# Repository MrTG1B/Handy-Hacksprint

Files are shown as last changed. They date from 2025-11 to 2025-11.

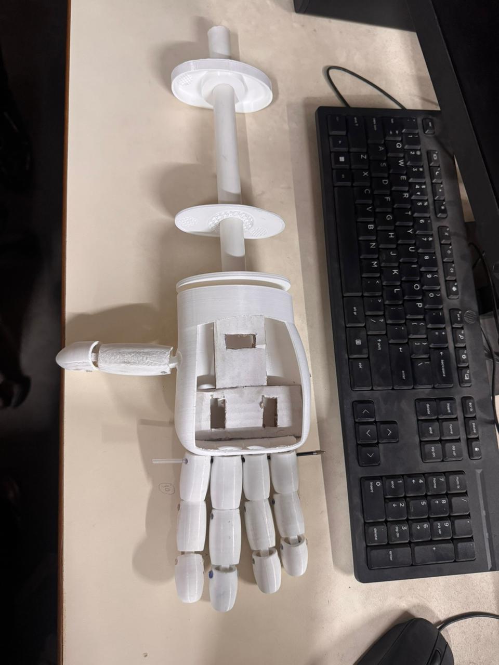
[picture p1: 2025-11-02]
Media/Handy- shell 2.jpg

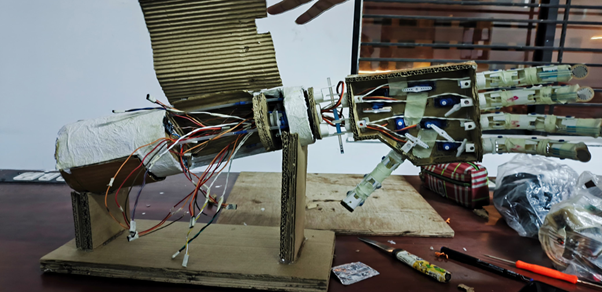
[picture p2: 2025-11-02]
Media/Handy- cardboard prototype.png

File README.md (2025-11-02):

# 🦾 Affordable & Functional Upper Limb Prosthetic Terminal Device  

### Development of an Affordable and Functional Upper Limb Prosthetic Terminal Device for Partial Hand Amputees  

This project aims to develop a **cost-effective, mechanically operated prosthetic terminal device (hand)** for upper limb amputees — bridging the gap between **high-cost myoelectric prostheses** and **low-function body-powered devices**.  

A large number of patients in India, especially in **rural and semi-urban regions**, remain underserved due to the lack of affordable and functional prosthetic devices.  
This project addresses that need directly.  

---

## 🎯 The Problem  

High-cost myoelectric prostheses are **financially inaccessible** for many, while **basic body-powered hooks** offer limited functionality and cosmetic appeal.  
There is a significant need for a device that is:  

- 💸 **Affordable:** Accessible to patients in low-resource settings.  
- 🧠 **Functional:** Capable of performing daily tasks reliably.  
- 🤲 **Intuitive:** Easy to operate and control.  
- ⚙️ **Robust:** Durable, water-resistant, and easy to maintain.  

---

## 💡 Our Solution  

The proposed device combines **mechanical simplicity** with **modern, cost-effective technology**.  
It is designed to be lightweight, easily repairable, and compatible with average anthropometric measurements of the human hand.  

### 🔧 Key Innovations  

#### 1. Affordable Control System  
- Integration of **cost-effective EMG (electromyography) sensors** for intuitive, muscle-based control.  
- A **smartphone app (via Bluetooth)** enables easy calibration, grip pattern selection, and fine-tuning.  
- This **hybrid approach** provides functionality similar to advanced myoelectric systems—without the high cost.  

#### 2. Servo Motor-Driven Gear System  
- A **servo motor-based gear drive** ensures strong and reliable grip control.  
- Enables secure handling of everyday items like utensils, bottles, and light tools.  

#### 3. Cost-Effective Manufacturing  
- Fabricated using **lightweight, locally available materials** and **basic manufacturing techniques**.  
- Designed for **easy repairs** and **affordable production** at scale.  

---

## ✨ Expected Features & Outcomes  

| Feature | Description |
|---|---|
| 💰 **Low Cost** | Significantly more affordable than current market prostheses. |
| 🤖 **Secure Grip** | Servo motor-based mechanism ensures efficient and safe object handling. |
| 📱 **Hybrid Control** | Combines EMG sensors with a Bluetooth smartphone app for easy control and calibration. |
| 🧩 **Practical Design** | Lightweight, water-resistant, and easy to maintain for daily use. |

---

## 👥 Target Audience  

This device is **primarily intended for partial hand amputees**.  
Our focus is on providing a **functional and accessible** prosthetic solution for individuals in **rural and semi-urban India**, who often lack access to affordable prosthetic care.  

---

## 🤝 Contributing  

We are actively developing this solution and welcome:  
- 💬 Feedback  
- 🔧 Contributions  
- 🤝 Collaborations and Partnerships  

If you are interested in supporting or joining this initiative, please feel free to **open an issue**, **submit a pull request**, or **reach out to us directly**.  

---

## 🌍 Vision  

> “To make functional prosthetic technology accessible to all — regardless of economic background.”  

Together, we can empower individuals with the tools they need to regain independence and confidence.  

---

### 🏷️ Keywords  
`Prosthetics` `Affordable Innovation` `Assistive Technology` `EMG Control` `Biomedical Engineering` `Human-Centered Design` `India`

---

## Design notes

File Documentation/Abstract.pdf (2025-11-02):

### Project Title: A Contextually Affordable and Modular Prosthetic Hand Platform for Partial Hand Amputees in India

The Problem: The Upper Limb Neglect Paradox
Upper limb amputation presents a profound public health challenge in India, particularly among young, rural males from low-income backgrounds whose livelihoods depend on strenuous manual labor. Existing prosthetic solutions suffer from a critical mismatch with the user's context: high-end myoelectric devices (costing 90000 Rupees to over 42 lakh Rupees) are prohibitively expensive, delicate, and unsuitable for the dusty, rugged environments of agricultural and industrial work. Conversely, conventional low-cost or bodypowered options are often non-functional, uncomfortable, or lack durability. The systemic failure lies not just in the initial cost, but in the total cost of ownership, as 62% of existing devices eventually require repairs, which are often inaccessible or too expensive. This situation creates a cycle of economic devastation and psychological trauma for amputees, demanding a solution rooted in radical affordability and real-world robustness.

The Solution: A Modular, Tiered Prosthetic Architecture
We propose the development of an Affordable and Functional Upper Limb Terminal Device built on a Modular, Tiered Architectural Platform. This design decouples the mechanical hand from the control interface, creating an accessible ecosystem with an estimated component cost for the entry-level model of under 5000 Rupees (less than 60 US Dollars). Our solution strategically combines the robustness of mechanical systems with the efficiency of low-cost, decentralized manufacturing and smart electronics. The core innovation is the Three-Tiered Control Strategy, allowing the same durable mechanical hand to be controlled by three distinct, progressively advanced interfaces, catering to diverse physiological needs, technical expertise, and financial capacities of the user population.

The Three Control Tiers:

a. Tier 1 (Ultra-Low-Cost): Push-Button Control: This entry point utilizes one or more simple push-buttons or toggle switches integrated into the prosthetic socket. The switch provides a basic binary (on/off) signal to the microcontroller, triggering a pre-programmed open or close sequence for the hand. This approach minimizes both cost and complexity, making a functional, motorized device available to the largest number of users, especially those who cannot generate usable myoelectric signals.
b. Tier 2 (Intermediate): Body-Actuated Switch Control: This system employs a simplified, single-cable harness connected to a small electronic switch inside the forearm shell. A gross body movement (such as a shoulder shrug) pulls the cable just enough to activate the switch. Activating the switch sends a signal to the microcontroller to power the servo motor, closing the hand. This hybrid retains the intuitive physical feedback of a harness while replacing the physically demanding task of generating grip force with an effortless, motor-powered grasp.
c. Tier 3 (Advanced): Low-Cost Myoelectric (EMG) Control: This tier integrates low-cost, commercially available EMG sensors (for example, MyoWare). The microcontroller reads the EMG signal's amplitude. On-Off Control: If the amplitude crosses a pre-set threshold, it activates the motor to close the hand. Proportional Control: The speed or force of the motor can be made proportional to the intensity of the muscle contraction. By using affordable, open-source-friendly sensors and microcontrollers, this provides intuitive myoelectric control accessible at a fraction of the cost of commercial systems.

Technical Blueprint and Innovation
The mechanical integrity is ensured through Fused Deposition Modelling (FDM) Three Dimensional Printing using a hybrid material approach: rigid, low-cost PLA for structural components, and flexible, high-friction TPU for integrated springs and gripping surfaces, enhancing durability and feel. The actuation system leverages ubiquitous, low-cost DC servo motors (for example, TowerPro MG995) coupled with a high-ratio Worm Gearbox integrated into the palm. This gearbox is essential for torque amplification, allowing us to achieve a functional pinching force (target eight Newton-meters) while critically enabling a selflocking feature to maintain grip without continuous battery drain—a vital feature for all-day use in energy-insecure environments. The hand employs an underactuated tendon-driven system, allowing the fingers to passively conform and securely grasp irregularly shaped objects with a single motor, minimizing complexity and weight.

Design for Maintainability (DfM) and Sustainability
Crucially, the design is underpinned by Design for Maintainability (DfM) principles to address the systemic failure of post-sale support. The device is fully modular, with individual finger assemblies, the actuation block, and the control module designed as easily replaceable units (analogous to Orbital Replacement Units - ORUs). All internal components are standardized, Commercial-Off-The-Shelf (COTS) parts, ensuring local sourcing and low-cost repair by local technicians using simple tools. By using India-specific anthropometric data for parametric scaling, we guarantee superior ergonomic fit, directly reducing a major cause of prosthetic rejection. The entire project is committed to an Open-Source Development Model, fostering community collaboration and enabling local entrepreneurs and Non-Governmental Organizations to adopt, fabricate, and support the device independently. This shifts the definition of affordability from the initial purchase price to the long-term, sustainable total cost of ownership.

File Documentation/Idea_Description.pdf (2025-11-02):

### Project Idea Description: Modular, Sustainable, and Contextually Appropriate Prosthetic Hand Platform

### 1. Contextual Problem Statement and Justification

The need for an affordable, high-functioning upper limb prosthesis in India is severe and critically underserved. Epidemiological data confirms that the target demographic is predominantly young, economically impoverished, rural males engaged in manual and agricultural labor, where trauma from machinery is the leading cause of amputation (70.3%). Current solutions fail because they are either economically unattainable (myoelectric models at 90,000 Rupees to 42 lakh Rupees) or functionally inadequate or uncomfortable (body-powered devices). The high cost and complexity of commercial prostheses, coupled with their sensitivity to the dust, moisture, and mechanical stress of the typical rural environment, lead to alarmingly low adoption (40% fitment rate) and high abandonment rates. Our solution addresses this by defining functionality not merely as dexterity, but as sustained durability and local maintainability within the user's harsh life context. The goal is to break the vicious cycle of poverty and disability by providing a viable tool for regaining economic independence.

### 2. Architectural Blueprint: The Three-Tiered Control System

The core innovation is a platform architecture that separates the robust, FDM-printed mechanical hand from the control interface. This modularity allows for mass customization and a phased upgrade path, ensuring that a functional, motorized hand is accessible to all income levels and physiological conditions.

Tier 1: Ultra-Low-Cost Push-Button Control
a. Mechanism: Simplest, most reliable, and lowest-cost entry point. Control is achieved via one or two robust, tactile push-buttons integrated into the socket or a simple wrist strap.
b. Functionality: A single press of the button initiates a pre-programmed Close sequence for the hand, driven by the onboard servo motor. A subsequent press triggers the Open sequence. This binary control is managed by a low-power microcontroller (for example, ESP32 or Arduino Nano).
c. Rationale: This tier provides an immediate, motorized functional improvement over a passive hand at minimal cost. It is a critical option for users with severe nerve damage or insufficient residual muscle mass for myoelectric control.

Tier 2: Intermediate Body-Actuated Switch Control (Hybrid System)
a. Mechanism: Blending the advantages of mechanical and electronic control. A simplified, non-loadbearing harness and single cable are used to actuate a small, internal electronic micro-switch (not to pull the tendons).
b. Functionality: A gross body movement (for example, shoulder forward flexion or abduction) pulls the cable just enough to momentarily close the micro-switch, sending a signal to the microcontroller to power the hand to close. Releasing the movement signals the hand to open.
c. Rationale: This offers an intuitive control scheme, retaining the user's innate sense of proprioceptive feedback from the cable tension, while offloading the physically demanding task of generating high grip force to the electric motor. It is highly robust against environmental factors as it avoids external EMG sensors.

Tier 3: Advanced Low-Cost Myoelectric (EMG) Control
a. Mechanism: Integration of low-cost, open-source-friendly surface EMG sensors (such as the MyoWare or similar DIY circuits) positioned over the residual flexor and extensor muscles.
b. Functionality: The microcontroller reads the amplified analog EMG signal. Control can be implemented via a simple On-Off Threshold (signal above threshold closes hand; below opens hand) or, more advanced, Proportional Control, where the speed and force of the grip are proportional to the intensity of the muscle contraction, allowing for nuanced, natural-feeling control.
c. Rationale: This provides the most intuitive user experience at a fraction of the cost of commercial systems, utilizing readily available electronic components and open-source control algorithms to manage complexity.

### 3. Actuation and Power Transmission System

The mechanical heart of the device is designed for high efficiency, compactness, and strength.

a. Actuators: Standard, readily available hobby-grade DC Servo Motors (for example, TowerPro MG995 for main actuation) are used due to their ubiquitous presence and low cost (94 Rupees to 350 Rupees per unit in India). They are directly controlled by PWM signals from the microcontroller.
b. Torque Amplification: To achieve a target pinch force of 8 Newton-meters required for manipulating tools and heavy objects, a high-ratio Worm Gearbox mechanism is integrated into the 3D-printed palm housing. The worm gear provides the necessary torque increase and offers the critical benefit of being self-locking. Once the hand grips an object, the gear mechanism holds the position without requiring continuous power draw from the motor, drastically conserving battery life and ensuring a secure hold.
c. Underactuated Tendon System: To minimize cost, weight, and component count, the hand utilizes an underactuated mechanism where a single primary motor drives the four fingers via high-strength braided fishing line (tendons) routed through internal channels. This configuration allows the fingers to naturally flex and conform to irregularly shaped objects in an adaptive grasp pattern, maximizing contact and security. Elastic TPU components or cords provide the passive return (opening) force.

### 4. Fabrication, Materials, and Ergonomics

a. Decentralized Fabrication: All structural components are fabricated using Fused Deposition Modelling (FDM) 3D printing, enabling cheap, rapid, and decentralized production in local maker spaces, directly addressing the geographic access chasm.
b. Hybrid Material Strategy: The components use a combination of low-cost materials: Polylactic Acid (PLA) for the rigid structural parts (palm, socket, phalanges) due to its strength and ease of printing, and Thermoplastic Polyurethane (TPU) for the compliant fingertips, palm pads, and integrated hinges. TPU offers high friction for superior grip and durability against abrasion.
c. Anthropometric Design: A major factor in rejection is poor fit. The device is parametrically designed using India-specific anthropometric data for hand lengths, breadths, and finger dimensions (for example, male mean hand length is approximately 192 point 8 millimeters, female is approximately 169 point 6 millimeters), ensuring that the final print is perfectly scaled to the user's anatomy based on simple caliper

measurements.

### 5. Cost Validation and Sustainability (Design for Maintainability)

The project is grounded in verifiable affordability. Our preliminary Bill of Materials (BOM) for the Tier 1 Push-Button Control model totals approximately 4,199 Rupees in retail component costs, achieving a 95% cost reduction compared to commercial myoelectric devices.

Sustainability is guaranteed through Design for Maintainability (DfM) principles:

a. Modularity: The hand is structured as easily separable modules (fingers, actuation block, control module). If a finger is damaged, only that part needs re-printing (material cost of a few Rupees), maximizing uptime and minimizing repair cost.
b. Standardization: Exclusive use of Commercial-Off-The-Shelf (COTS) components (standard servo motors, metric fasteners, common microcontrollers) ensures local sourcing of spare parts, eliminating dependency on proprietary supply chains and vendor lock-in.
c. Open-Source Model: All CAD files, code, and documentation will be released under a permissive license, encouraging global and local iteration, community support, and the establishment of local repair and fitting networks by NGOs and local entrepreneurs.

This holistic approach transforms the project from a one-off device into a sustainable, scalable platform, providing enduring functional value to a critically underserved population.

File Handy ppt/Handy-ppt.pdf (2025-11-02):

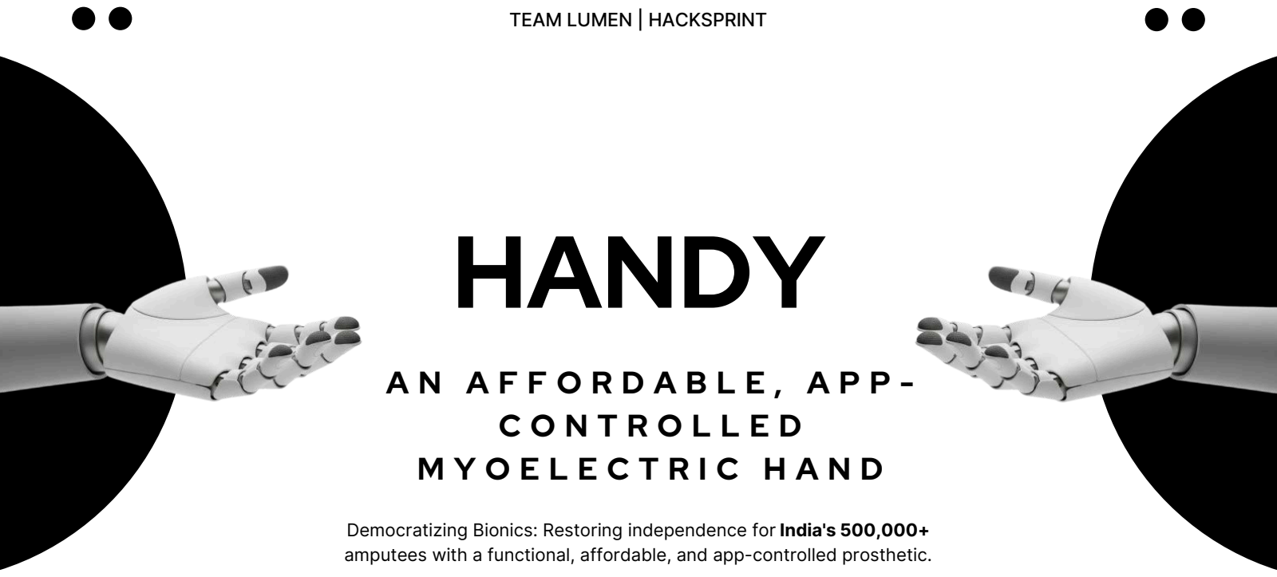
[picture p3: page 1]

# HANDY

# A N A F F O R D A B L E , A P P -C O N T R O L L E D M Y O E L E C T R I C H A N D

Democratizing Bionics: Restoring independence for India's 500,000+ amputees with a functional, affordable, and app-controlled prosthetic.

TEAM LUMEN | HACKSPRINT

# A CRISIS OF

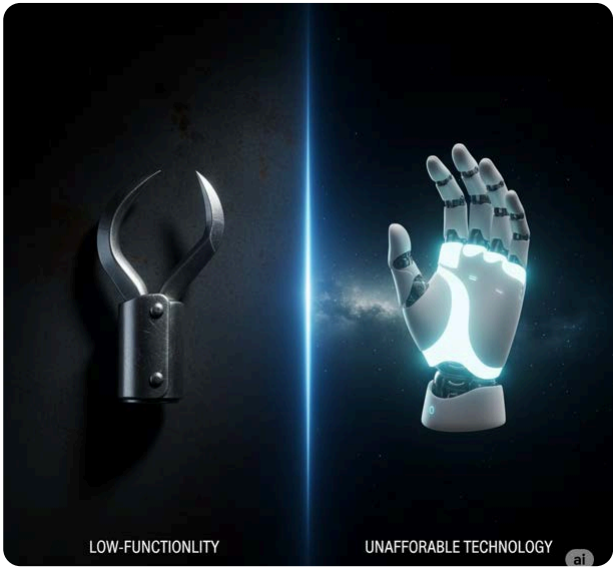
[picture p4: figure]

# ACCESSIBILITY

### In India, over 500,000 people with upper-limb loss face a heartbreaking choice: basic, nonfunctional claws or imported bionic hands costing over ₹10 lakhs. With an estimated 95%

of users unable to afford modern solutions, millions are excluded from employment, independence, and dignity.

TEAM LUMEN | HACKSPRINT | PAGE 02

# THE UNSOLVABLE CHOICE

# OUR SOLUTION: DEMOCRATIZING BIONICS

Introducing Handy: A functional, app-controlled myoelectric hand that directly solves the accessibility crisis. It's the first step in our mission, delivering functional independence at a price point that is accessible to all.

TEAM LUMEN | HACKSPRINT | PAGE 03

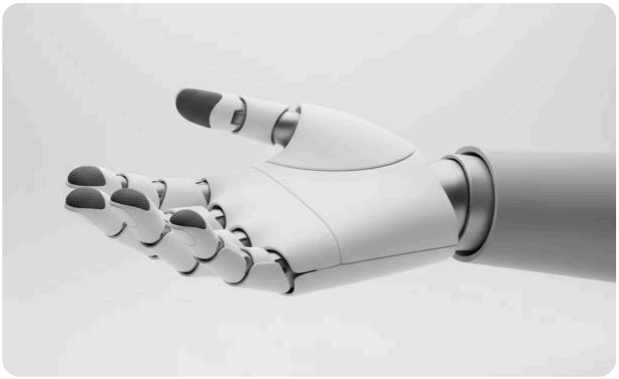
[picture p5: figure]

By using low-cost components like the ESP32, servo motors, and 3D printing, we achieve a target component cost of under ₹5,000—a 95%+ reduction on commercial devices.

RADICAL AFFORDABILITY

A user selects a desired grip (e.g., "Palmar", "Pinch") in our custom mobile app. A simple muscle flex, read by an sEMG sensor, then commands the hand to perform the action.

APP-CONTROLLED FUNCTIONALITY
01

02

# HOW IT WORKS: APP-CONTROLLED MYOELECTRICITY

Handy uses a robust and reliable system that combines a simple mobile app with proven sEMG sensor technology. This allows for precise, pre-selected grip patterns to be executed with a simple, intuitive muscle flex.

TEAM LUMEN | HACKSPRINT | PAGE 04

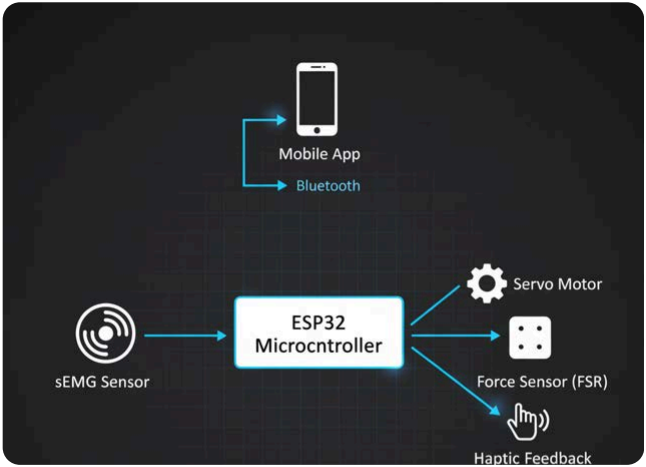
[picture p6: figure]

When the user is ready, a simple flex of their muscle (e.g., bicep) is detected by the sEMG sensor. The ESP32 reads this signal as the "go" command and actuates the servo motors to perform the pre-selected grip .

EXECUTION VIA MUSCLE FLEX

The user selects a desired functional grip, like "Palmar" or "Pinch," from our custom mobile app. This command is sent to the hand's ESP32 microcontroller via Bluetooth and "arms" the hand for the action .

GRIP SELECTION VIA APP
01

02

# OUR IMPACT: FROM PROHIBITIVE COST TO EMPOWERING POSSIBILITY

Handy isn't just a device; it's a catalyst for change. By making functional prosthetics radically affordable, we directly address the socio-economic barriers that exclude millions, creating a tangible impact on individual lives and the national MedTech landscape.

TEAM LUMEN | HACKSPRINT | PAGE 05

Delivers the dexterity of a ₹10L+ limb at a 95%+ cost reduction, making advanced technology accessible for the first time.

RADICAL AFFORDABILITY

Empowers users to perform complex daily tasks with confidence, increasing the chances of rejoining the workforce by up to 3x.

RESTORED INDEPENDENCE

Provides a functional, lifelike prosthetic that restores not just ability, but also self-respect, identity, and psychological well-being .

ENHANCED DIGNITY & WELL-BEING

Strengthens India's Atmanirbhar Bharat mission in MedTech by developing a world-class, scalable, and locally manufactured solution.

BOOSTING INDIAN INNOVATION

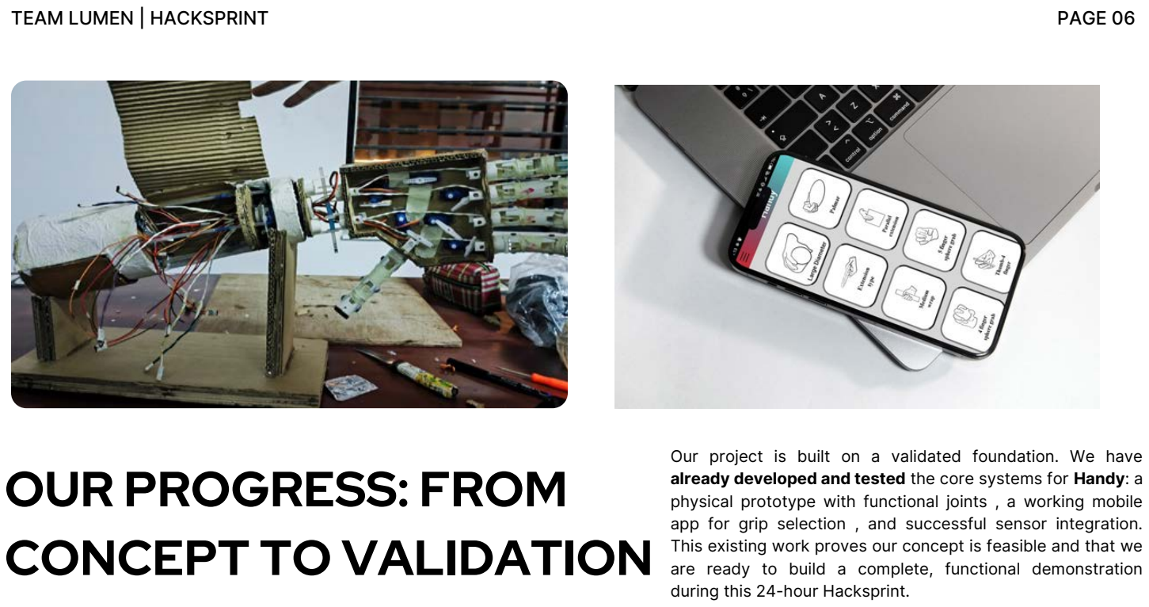
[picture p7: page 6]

# OUR PROGRESS: FROM CONCEPT TO VALIDATION

Our project is built on a validated foundation. We have already developed and tested the core systems for Handy: a physical prototype with functional joints , a working mobile app for grip selection , and successful sensor integration. This existing work proves our concept is feasible and that we are ready to build a complete, functional demonstration during this 24-hour Hacksprint.

TEAM LUMEN | HACKSPRINT | PAGE 06

# TECHNICAL ARCHITECTURE: OUR HACKSPRINT BUILD

Our system for Handy is built on a modular, low-cost architecture perfect for rapid prototyping in 24 hours. The ESP32 microcontroller is the central hub, receiving grip commands from our mobile app via Bluetooth. It then waits for a simple trigger from the sEMG sensor to execute the action, driving the servo motors with precision.

TEAM LUMEN | HACKSPRINT | PAGE 07

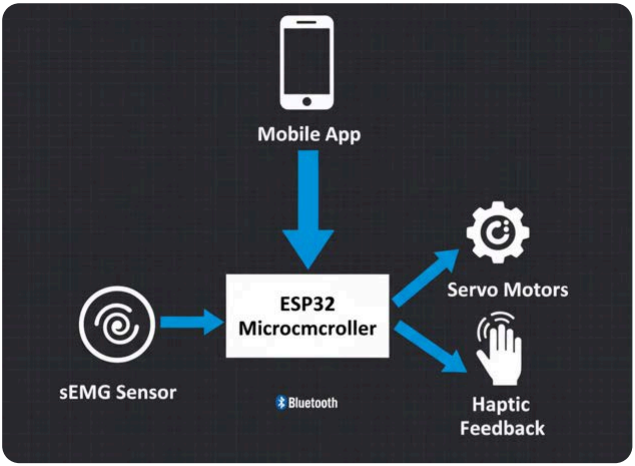
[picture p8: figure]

# OUR ROADMAP:

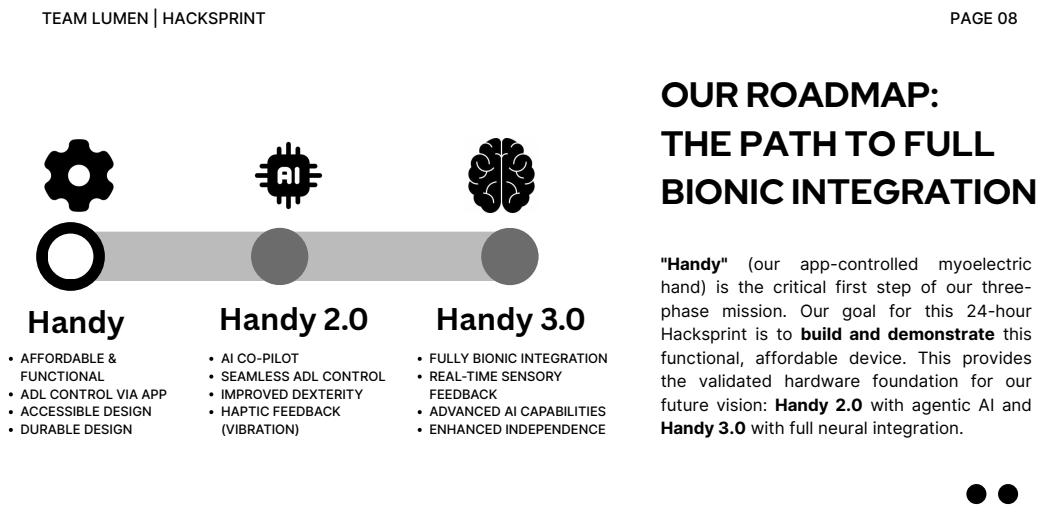
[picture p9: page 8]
TEAM LUMEN | HACKSPRINT; PAGE 08; Handy; Handy 2.0; Handy 3.0

THE PATH TO FULL
BIONIC INTEGRATION

"Handy" (our app-controlled myoelectric
hand) is the critical first step of our three-
phase mission. Our goal for this 24-hour
Hacksprint is to build and demonstrate this
functional, affordable device. This provides
the validated hardware foundation for our
future vision: Handy 2.0 with agentic AI and
Handy 3.0 with full neural integration.

AFFORDABLE &
FUNCTIONAL
ADL CONTROL VIA APP
ACCESSIBLE DESIGN
DURABLE DESIGN

AI CO-PILOT
SEAMLESS ADL CONTROL
IMPROVED DEXTERITY
HAPTIC FEEDBACK
(VIBRATION)

FULLY BIONIC INTEGRATION
REAL-TIME SENSORY
FEEDBACK
ADVANCED AI CAPABILITIES
ENHANCED INDEPENDENCE

Our App-Controlled Myoelectric System is the core innovation for this build. It provides intuitive, multi-grip functionality at a 95%+ cost reduction, making it a truly disruptive and accessible
platform.

HIGHLY INNOVATIVE

Dramatically reduces cost by over 95% and can increase a user's chances of rejoining the workforce by 3x, restoring dignity and independence.

IMMENSELY IMPACTFUL
Targets a ₹700 Cr+ Indian
market. Capturing just 1%
of this need represents a
massive opportunity for a
self-sustaining social
enterprise.

FINANCIALLY VIABLE

Built with low-cost, offthe-shelf components like
the ESP32 and 3D-printed
materials, achieving a
functional component cost
of just ₹4,200 .

TECHNICALLY FEASIBLE

TEAM LUMEN | HACKSPRINT | PAGE 09

# WHY HANDY WINS: A SUMMARY

Handy is a rare combination of practical innovation and immense impact. It is built on a validated, ultra-low-cost hardware foundation, targets a massive and underserved market, and delivers lifechanging benefits.

# THANK YOU

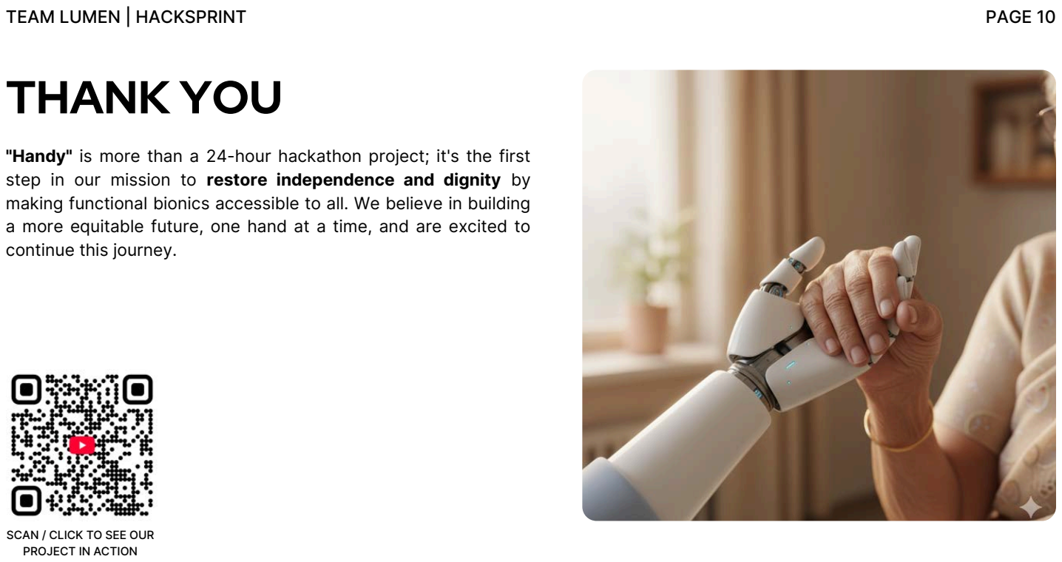
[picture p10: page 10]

TEAM LUMEN | HACKSPRINT | PAGE 10

"Handy" is more than a 24-hour hackathon project; it's the first step in our mission to restore independence and dignity by making functional bionics accessible to all. We believe in building a more equitable future, one hand at a time, and are excited to continue this journey.

SCAN / CLICK TO SEE OUR
PROJECT IN ACTION

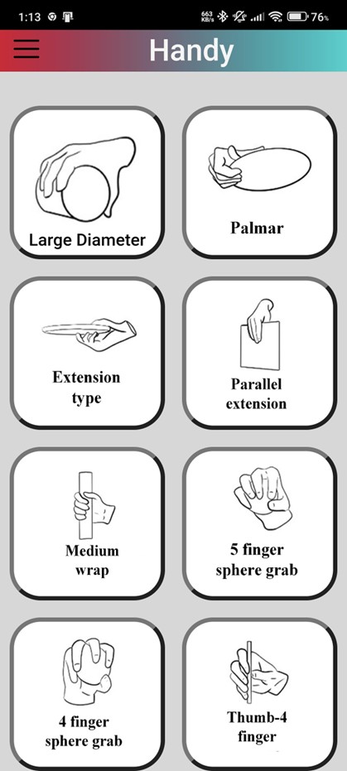
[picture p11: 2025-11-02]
Media/Handy- App UI.jpg

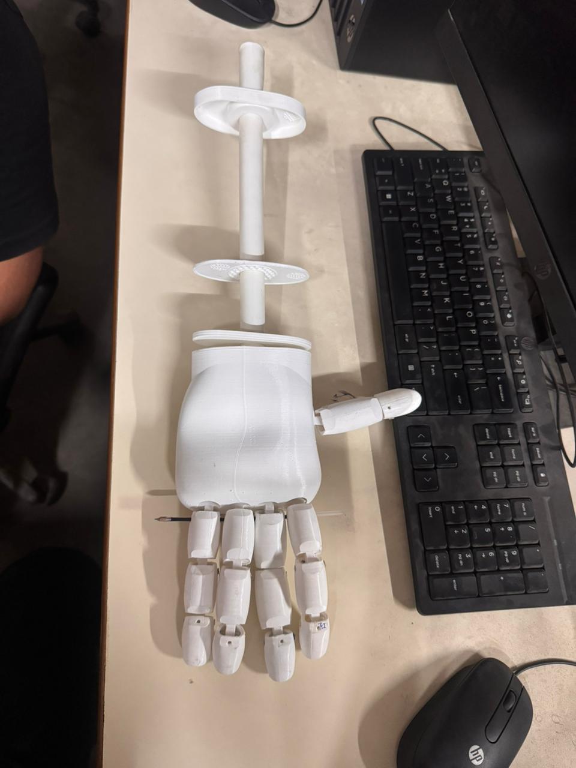
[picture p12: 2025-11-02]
Media/Handy- shell 1.jpg

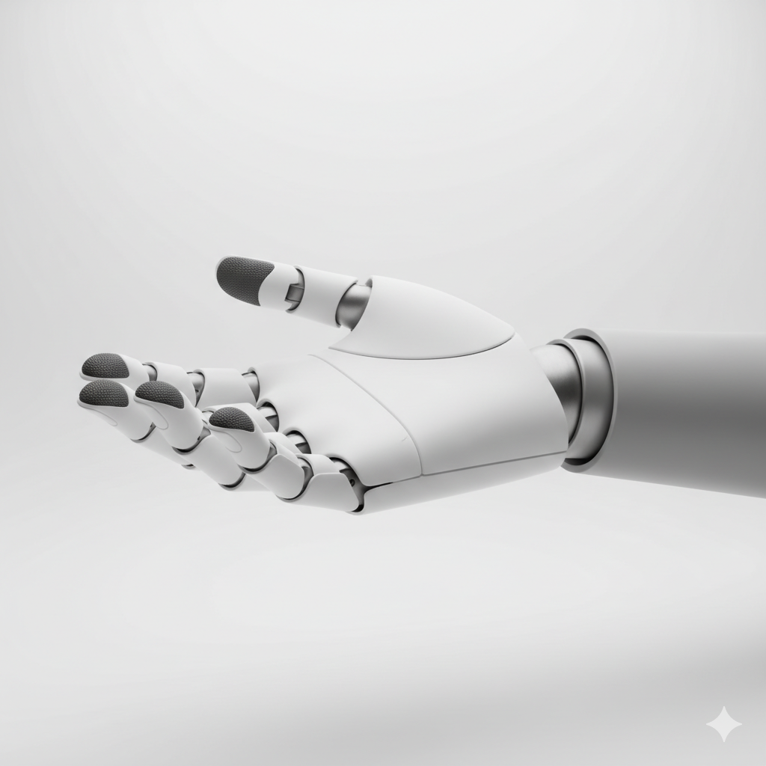
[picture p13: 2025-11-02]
Media/Handy- Product image.png

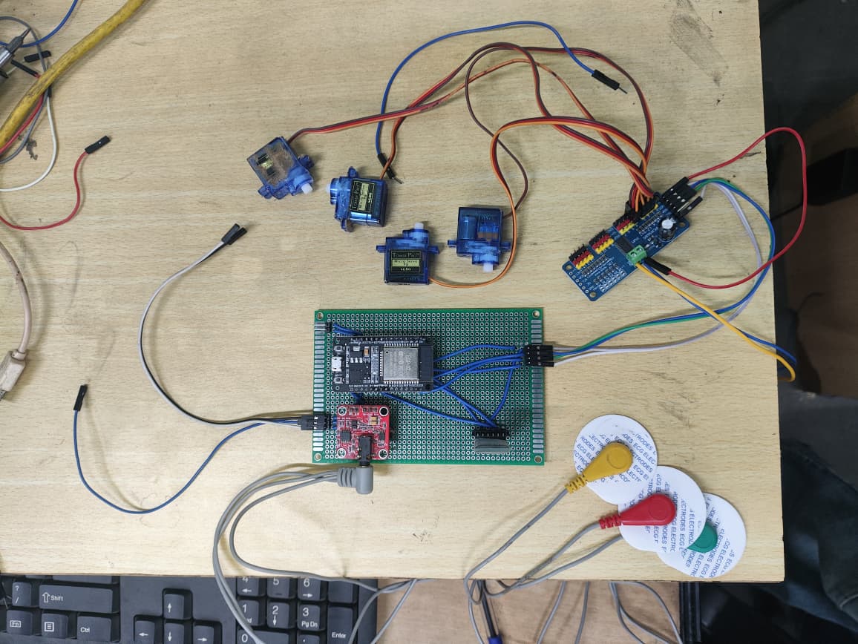
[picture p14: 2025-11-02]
Media/Handy-prototype circuit.jpg

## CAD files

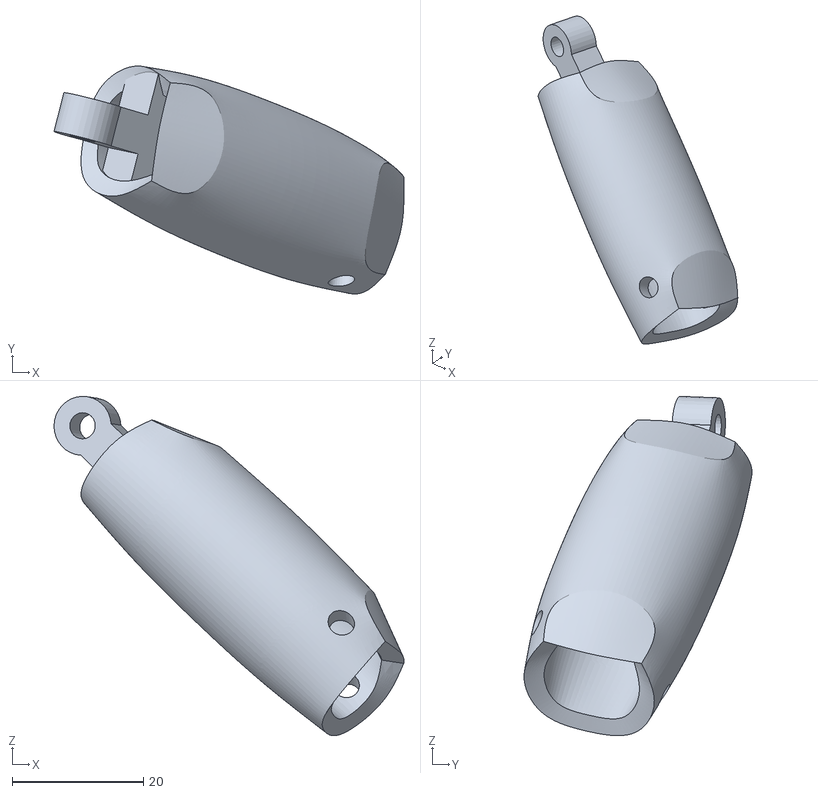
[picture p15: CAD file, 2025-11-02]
Design/STL-FILES/THUMB-2.stl
53.4 x 34.8 x 51.8

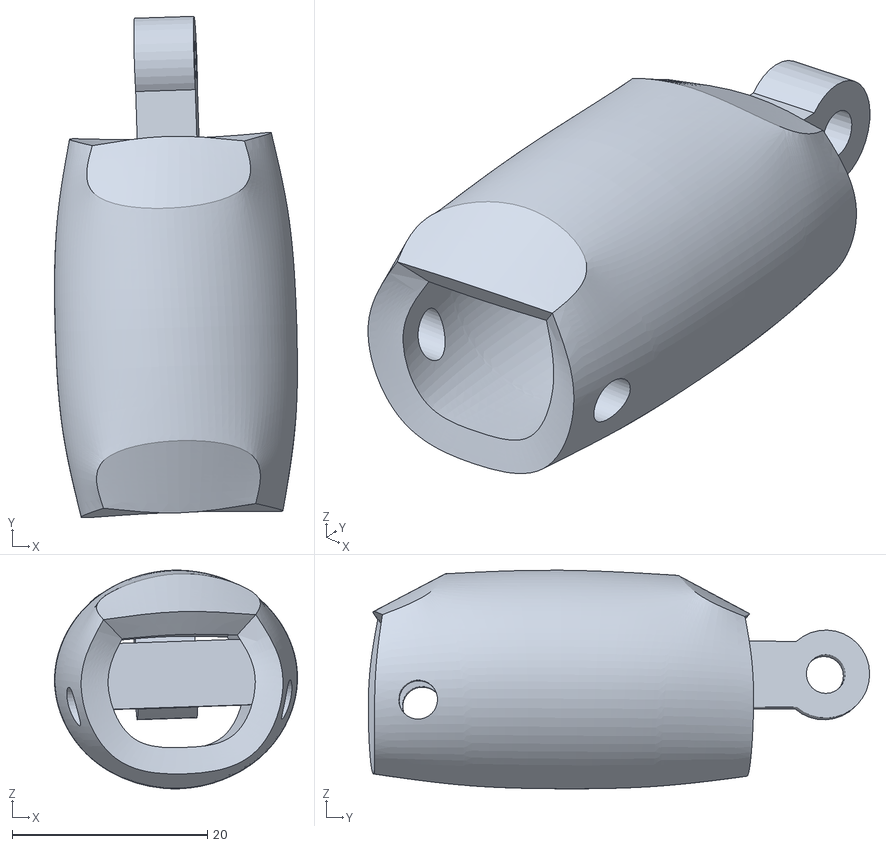
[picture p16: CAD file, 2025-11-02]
Design/STL-FILES/MIDDLE-3.stl
24.9 x 51.4 x 22.4

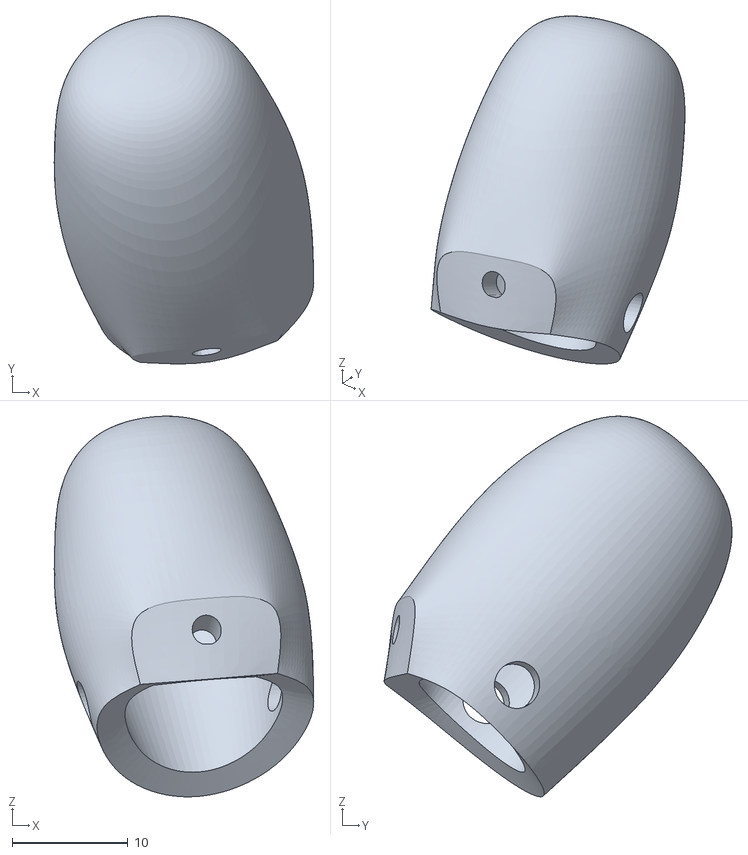
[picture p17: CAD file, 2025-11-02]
Design/STL-FILES/INDEX-1.stl
22.5 x 30.1 x 33.0

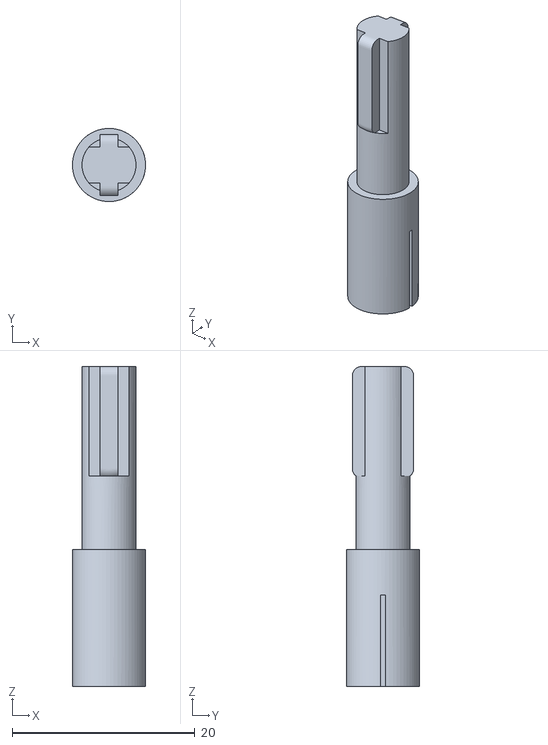
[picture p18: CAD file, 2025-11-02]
Design/STL-FILES/Grind2.stl
8.00 x 8.00 x 35.0

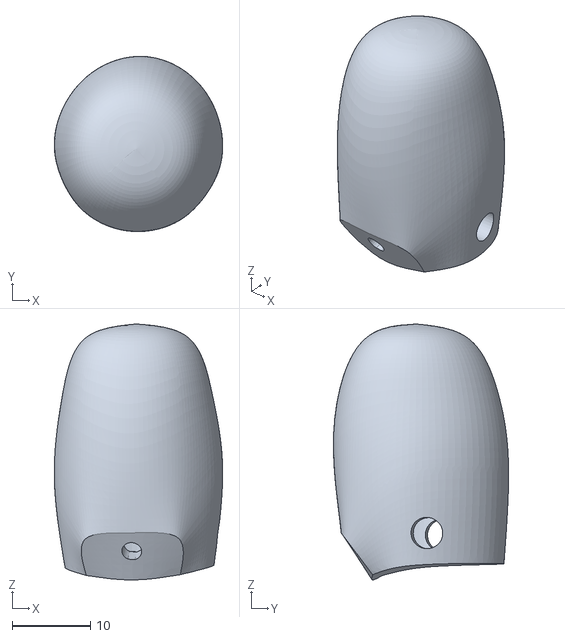
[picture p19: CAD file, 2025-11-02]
Design/STL-FILES/SMALL-1.stl
21.5 x 22.4 x 32.7

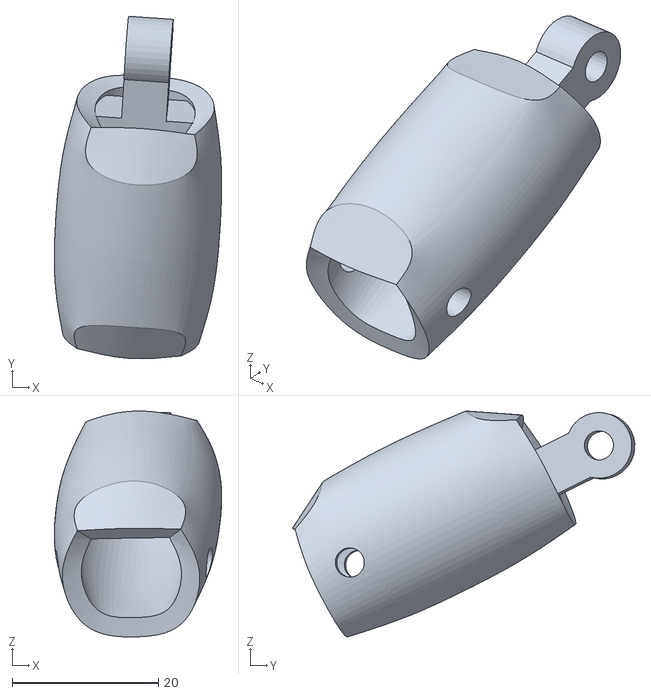
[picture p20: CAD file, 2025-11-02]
Design/STL-FILES/RING-2.stl
22.9 x 46.9 x 30.9

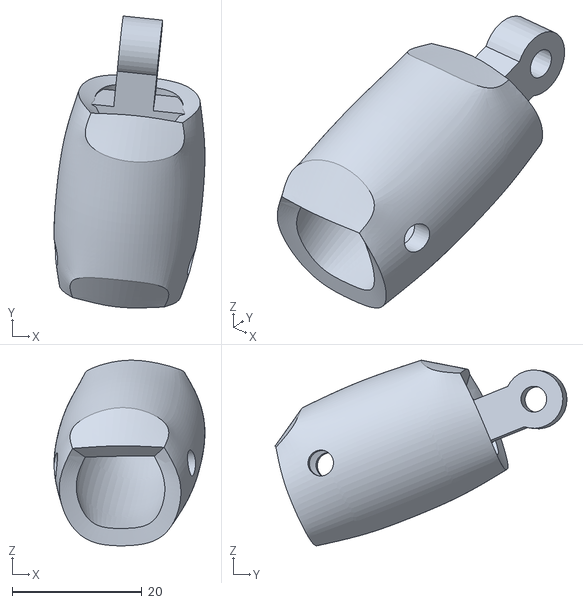
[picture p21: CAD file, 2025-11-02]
Design/STL-FILES/SMALL-3.stl
23.2 x 45.0 x 28.6

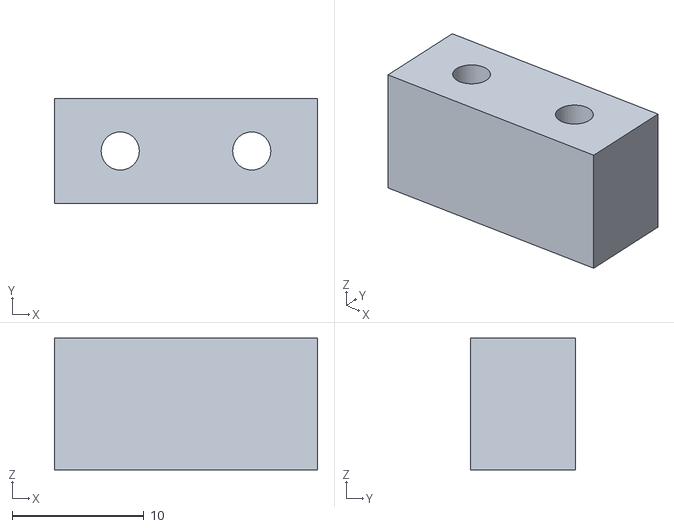
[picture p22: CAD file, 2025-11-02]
Design/STL-FILES/Swrew Connector v1.stl
20.0 x 8.00 x 10.0

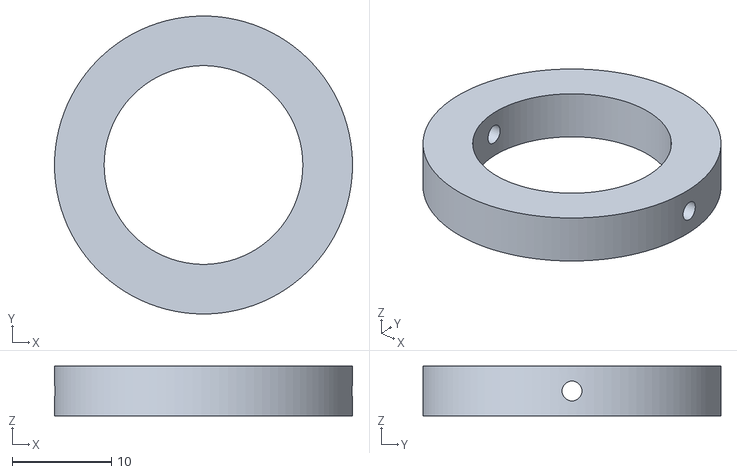
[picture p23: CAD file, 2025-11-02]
Design/STL-FILES/pipe_lock v1.stl
30.0 x 30.0 x 5.00

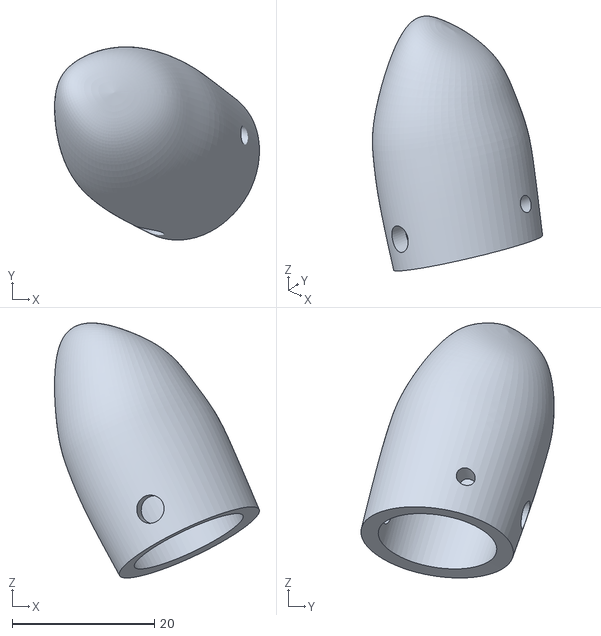
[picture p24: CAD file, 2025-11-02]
Design/STL-FILES/THUMB-1.stl
28.9 x 27.2 x 35.9

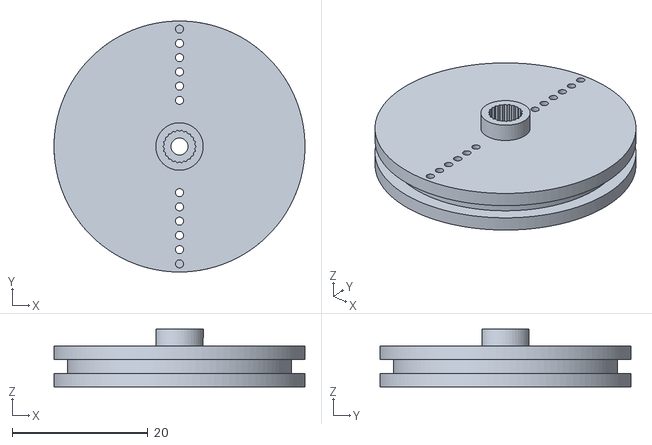
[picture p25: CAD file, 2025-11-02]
Design/STL-FILES/pully v1.stl
37.0 x 37.0 x 8.50

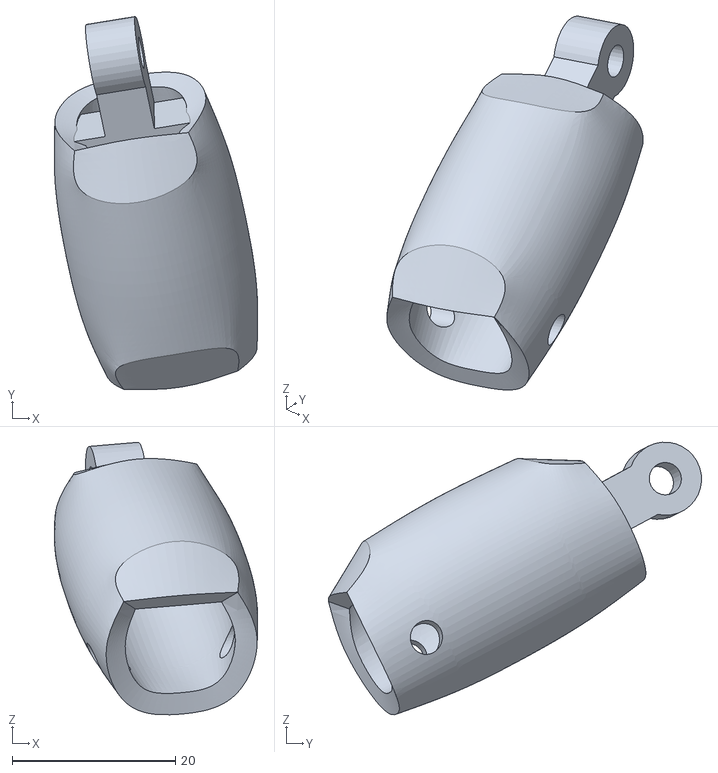
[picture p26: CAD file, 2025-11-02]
Design/STL-FILES/INDEX-3.stl
25.0 x 45.8 x 33.4

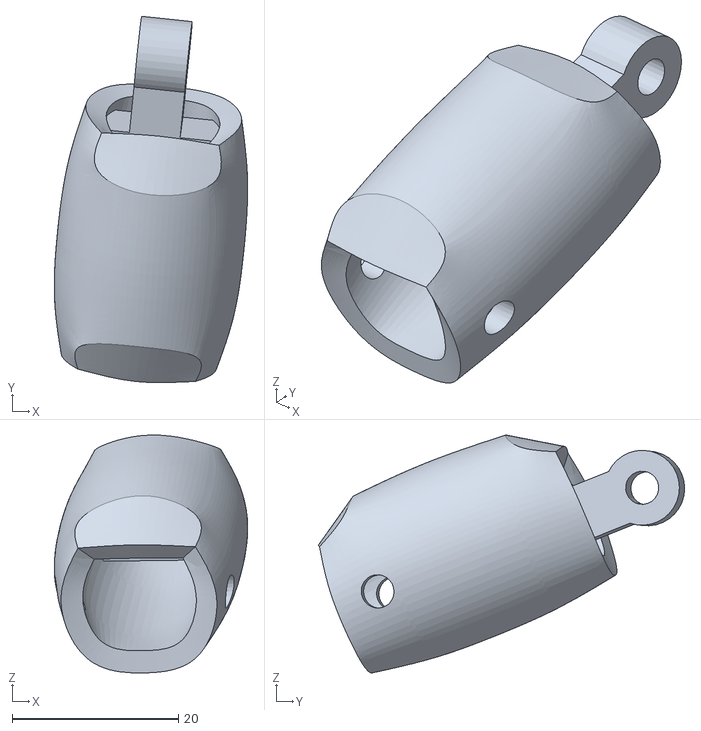
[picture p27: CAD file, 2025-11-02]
Design/STL-FILES/SMALL-2.stl
23.2 x 44.1 x 28.6

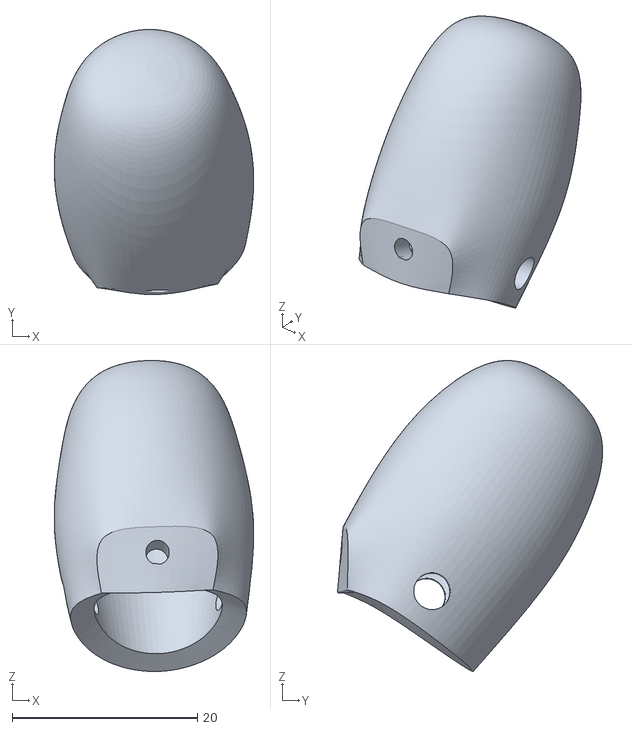
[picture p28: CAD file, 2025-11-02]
Design/STL-FILES/MIDDLE-1.stl
21.6 x 28.6 x 33.6

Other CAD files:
Design/STL-FILES/RING-1.stl
Design/STL-FILES/MIDDLE-2.stl
Design/STL-FILES/Grind.stl
Design/STL-FILES/INDEX-2.stl
Design/STL-FILES/BACK PLATE.stl
Design/STL-FILES/PALM.stl
Design/STL-FILES/RING-3.stl

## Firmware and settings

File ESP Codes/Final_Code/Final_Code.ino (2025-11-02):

#include <Wire.h>
#include <Adafruit_PWMServoDriver.h>
#include "HardwareSerial.h"

// Create a second hardware serial object for HM-10
HardwareSerial HM10(2); // Use UART2, which is GPIO16 (RX2) and GPIO17 (TX2)

// Initialize the PCA9685 driver
// We are using the default I2C address (0x40)
Adafruit_PWMServoDriver pwm = Adafruit_PWMServoDriver();

// ESP32 I2C Pins (default)
#define SDA_PIN 21
#define SCL_PIN 22

// Servo pulse length settings. These may need tuning
// for your specific servos.
#define SERVOMIN 150  // Min pulse length (0 degrees)
#define SERVOMAX 600  // Max pulse length (180 degrees)
#define SERVO_FREQ 50 // PWM frequency for analog servos (50Hz)


// Number of servos
const int NUM_SERVOS = 5;

// FSR and Motor Pins
const int numFSRs = 4;
const int fsrPins[numFSRs] = {32, 35, 34, 36};     // FSR pins array
const int motorPins[numFSRs] = {4, 5, 18, 19};     // Motor pins array

// EMG sensor pin and threshold
const int emgPin = 39;

// Thresholds
const int fsrThreshold = 500;  // Adjust based on your FSR sensitivity

// Bluetooth setup (using Serial2 for communication)
#define RXD2 16
#define TXD2 17

// bool commandExecuted = false; // REMOVED - Replaced by new state flags

String commandData="";

// --- New EMG Averaging and State Logic ---
// --- Fast Average (What the sensor is doing NOW) ---
const int fast_window_size = 5;
int fast_values[fast_window_size];
int fast_value_index = 0;
long fast_sum = 0;

// --- Long Average (The "center" or "baseline" signal) ---
const int long_window_size = 100; // Larger window to track the slow drift
int long_values[long_window_size];
int long_value_index = 0;
long long_sum = 0;

// --- Threshold ---
// This is the trigger for the 'deviation'. 
int threshold = 200; // You may need to tune this value

// --- State Tracking ---
bool flex_detected_flag = false;
bool switch_state = false; // false = Hand Open, true = Hand Gripped

typedef void (*CommandFunction)();

void setup() {
  // Initialize motor pins as outputs
  for (int i = 0; i < numFSRs; i++) {
    pinMode(motorPins[i], OUTPUT);
    digitalWrite(motorPins[i], LOW);  // Start with motors off
  }

  // Initialize EMG pin as input
  pinMode(emgPin, INPUT);

  // Initialize serial communication for HM-10 and debugging
  Serial.begin(115200);                        // Debugging on Serial Monitor
  
  Serial.println("PCA9685 Servo Test for ESP32");

  // Initialize I2C communication on the ESP32's pins
  Wire.begin(SDA_PIN, SCL_PIN);

  // Initialize the PCA9685 driver
  pwm.begin();
  
  // Set the PWM frequency
  pwm.setPWMFreq(SERVO_FREQ);

  Serial.println("Setup complete. Waiting for Bluetooth data...");
  
  HM10.begin(9600, SERIAL_8N1, RXD2, TXD2); // HM-10 on Serial2 (Pins 16 and 17)
  
  // --- EMG CALIBRATION ---
  Serial.println("Calibrating EMG... Please relax for a few seconds.");
  // Initialize both value arrays
  for (int i = 0; i < fast_window_size; i++) {
    fast_values[i] = 0;
  }
  for (int i = 0; i < long_window_size; i++) {
    long_values[i] = 0;
  }

  // Prime the averages with initial readings to avoid a long startup
  for (int i = 0; i < long_window_size; i++) {
    int initial_reading = analogRead(emgPin);
    long_values[i] = initial_reading;
    long_sum += initial_reading;
    
    // Also fill the fast average
    if (i < fast_window_size) {
      fast_values[i] = initial_reading;
      fast_sum += initial_reading;
    }
    delay(15); // Short delay to get good samples
  }
  Serial.println("Calibration complete. Ready to flex.");
  
  Serial.println("Waiting for Bluetooth data...");
}

void loop() {
  // Check for available data from Bluetooth
  if (HM10.available()) {
    commandData = HM10.readString(); // Read incoming character
    Serial.println("Stored command: " + commandData); 
  }

  // Handle FSR readings and control vibration motors
  for (int i = 0; i < numFSRs; i++) {
    int fsrValue = analogRead(fsrPins[i]);

    // Map FSR values to motor intensity (0-255 for PWM control)
    int motorIntensity = map(fsrValue, fsrThreshold, 4095, 0, 255); // Adjust 4095 if using a 10-bit ADC
    motorIntensity = constrain(motorIntensity, 0, 255); // Constrain to valid PWM range

    analogWrite(motorPins[i], motorIntensity); // Set motor intensity based on FSR value
  }
  
  // Check EMG data
  updateEmgState();
  delay(50); // Delay from new EMG logic
}

/**
 * @brief Reads EMG, updates averages, and toggles hand state.
 */
void updateEmgState() {
  // --- Read the new value ---
  int new_value = analogRead(emgPin);

  // --- 1. Calculate the Fast Average (your "current" signal) ---
  fast_sum = fast_sum - fast_values[fast_value_index];
  fast_values[fast_value_index] = new_value;
  fast_sum = fast_sum + new_value;
  fast_value_index = (fast_value_index + 1) % fast_window_size;
  float fast_avg = (float)fast_sum / fast_window_size;

  // --- 2. Calculate the Long Average (your "baseline" or "center") ---
  long_sum = long_sum - long_values[long_value_index];
  long_values[long_value_index] = new_value;
  long_sum = long_sum + new_value;
  long_value_index = (long_value_index + 1) % long_window_size;
  float long_avg = (float)long_sum / long_window_size;

  // --- 3. Calculate Deviation ---
  // This is now the difference between the fast and slow signals
  float deviation = abs(fast_avg - long_avg); 

  // --- Toggle Logic ---
  // Triggers if deviation goes ABOVE your threshold (e.g., 200)
  if (!flex_detected_flag && deviation > threshold) {
    switch_state = !switch_state; // Toggle the state
    flex_detected_flag = true;     // Mark that we just flexed
    
    if (switch_state) {
      Serial.println("EMG State: ON - Executing Command");
      executeCommand(commandData); // Perform the grip
    } else {
      Serial.println("EMG State: OFF - Opening Hand");
      openAllServos(); // Release the grip
    }
  }
  
  // --- Reset Logic ---
  // Resets when deviation drops BELOW 50% of threshold (e.g., 100)
  else if (flex_detected_flag && deviation < threshold * 0.5) { 
    flex_detected_flag = false; // Ready for next toggle
  }
}


void openAllServos() {
  for (int i = 0; i < NUM_SERVOS; i++) {
    setServoAngle(i, 0);
  }
  Serial.println("All five servos opened to 0 degrees.");
}

/**
 * @brief Sets the angle of a specific servo.
 * @param servoNum The servo number (0-15) to control.
 * @param angle The desired angle (0-180 degrees).
 */
void setServoAngle(uint8_t servoNum, int angle) {
  // Map the 0-180 degree angle to the min/max pulse length
  int pulseLength = map(angle, 0, 180, SERVOMIN, SERVOMAX);

  // Set the PWM for the specified servo
  // The '0' means the pulse starts at tick 0
  pwm.setPWM(servoNum, 0, pulseLength);
}


// Command functions
void func1() {
  for (int i = 0; i < 5; i++) { 
    setServoAngle(i, 90);
  }
}

void func2() {
  setServoAngle(0, 0);
  for (int i = 1; i < 5; i++) { 
    setServoAngle(i, 180);
  }
}

void func3() {
  setServoAngle(0, 180);
  setServoAngle(1, 45);
  setServoAngle(2, 90);
  setServoAngle(3, 135);
  setServoAngle(4, 180);
}

void func4() {
  setServoAngle(0, 180);
  for (int i = 1; i < 5; i++) { 
    setServoAngle(i, 30);
  }
}

void func5() {
  for (int i = 0; i < 5; i++) { 
    setServoAngle(i, 180);
  }
}

// Optimized: func6, 7, and 8 just call func5 to avoid duplicate code
void func6() { func5(); }

void func7() { func5(); }

void func8() { func5(); }

// Removed func9, func10, func11, func12 as they were for wrist control

void func13(){
  setServoAngle(0, 180);
  setServoAngle(2, 180);
  setServoAngle(3, 180);
  setServoAngle(1, 0);
  setServoAngle(4, 0);
}

void func14(){
  for(int i=0;i<5;i++)
  {
    setServoAngle(i, 180);
  }
  delay(100);
  setServoAngle(2, 0);
}



// Array of function pointers
CommandFunction functions[] = {
  func1, func2, func3, func4, func5, func6, func7,
  func8, func13, func14 // Removed func9, 10, 11, 12
};


void executeCommand(String command) {
  int index = command.toInt();  // Convert string to integer
  // Note: In Arduino, use sizeof(functions)/sizeof(functions[0]) instead of .length()
  if (index >= 1 && index <= sizeof(functions)/sizeof(functions[0])) {
    functions[index - 1]();  // Arrays are 0-based, so subtract 1
  } else {
    Serial.println("Unknown command received.");
  }
}

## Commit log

2025-11-02 Rename card.png to Handy- cardboard prototype.png
2025-11-02 Rename handy-prototype circuit.jpg to Handy-prototype circuit.jpg
